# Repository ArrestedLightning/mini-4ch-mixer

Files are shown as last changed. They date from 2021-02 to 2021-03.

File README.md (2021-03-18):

# Mini 4 Channel Audio Mixer

A very simple active audio mixer with 4 3.5mm inputs, and 1 3.5mm output.  USB-powered.  The default gain is 1:1 on all channels, although this can be changed by altering resistor values and/or installing potentiometers.  I built this as a simple way to run multiple sources into a set of computer speakers.  It is designed to fit in a commonly-available 90x70x28mm enclosure with end panels that can be either laser-cut or made from PCBs.

This project uses symbols from https://github.com/ArrestedLightning/al_kicad_libraries/.  It is licensed CC BY 4.0.

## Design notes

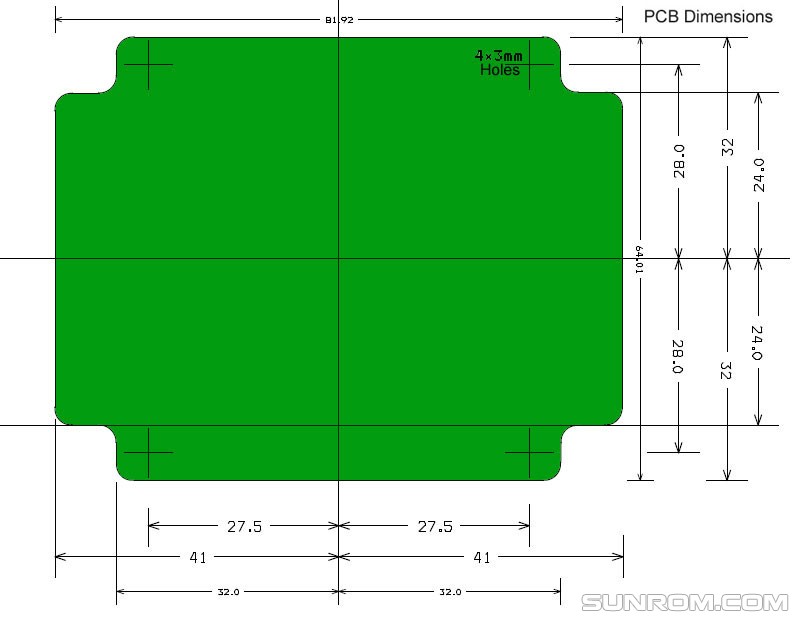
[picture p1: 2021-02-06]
artwork/pcbdim.jpg

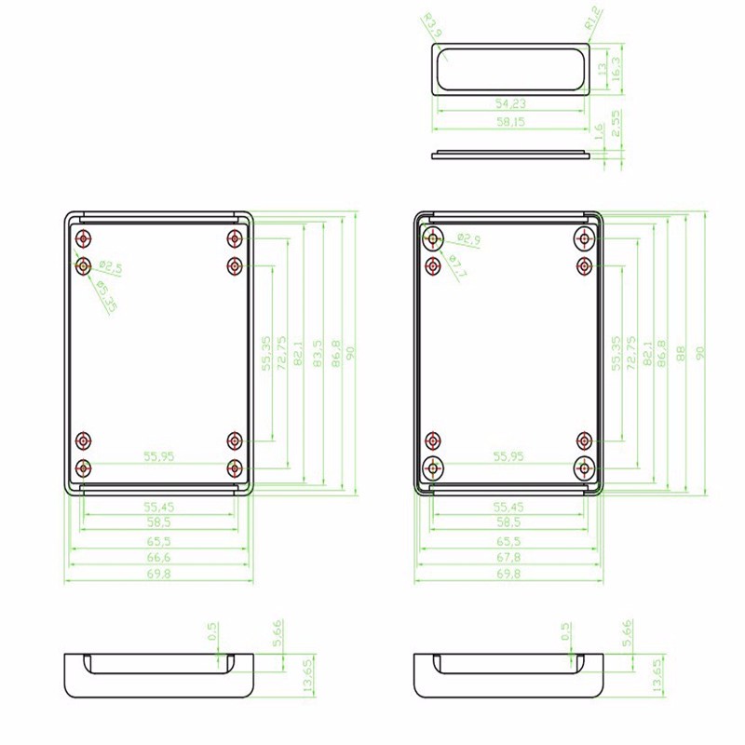
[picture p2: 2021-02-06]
artwork/casedim2.jpg

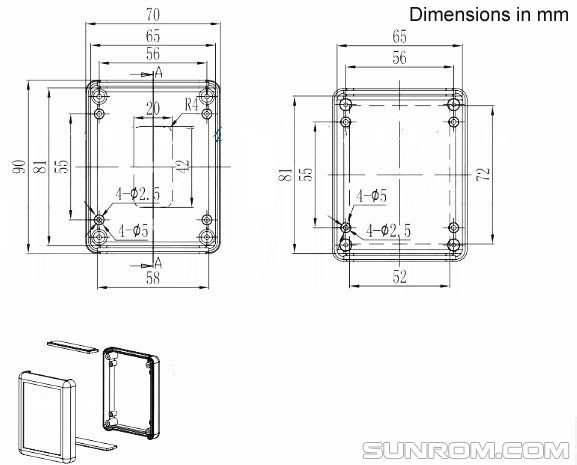
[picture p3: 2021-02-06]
artwork/casedim1.jpg

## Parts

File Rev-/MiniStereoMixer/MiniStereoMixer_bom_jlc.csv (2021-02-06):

Comment | Designator | Footprint | LCSC Part #
0.1uF | C14,C1,C2 | C_0805_2012Metric_Pad1.15x1.40mm_HandSolder | C49678
1uF | C15,C6,C10 | C_0805_2012Metric_Pad1.15x1.40mm_HandSolder | C28323
10uF | C17,C16,C18,C7,C11,C8,C12,C9,C13,C3,C5,C4,C19 | C_0805_2012Metric_Pad1.15x1.40mm_HandSolder | C15850
Blue | D1 | LED_0805_2012Metric_Pad1.15x1.40mm_HandSolder | C2293
White | D2 | LED_0805_2012Metric_Pad1.15x1.40mm_HandSolder | C34499
Ferrite_Bead_Small | FB1,FB2,FB3 | R_0805_2012Metric_Pad1.15x1.40mm_HandSolder | C1017
82K | R3,R6 | R_0805_2012Metric_Pad1.15x1.40mm_HandSolder | C17840
220K | R4,R5 | R_0805_2012Metric_Pad1.15x1.40mm_HandSolder | C17556
0 | R11,R13,R12,R14,R10,R9,R8,R7,R29 | R_0805_2012Metric_Pad1.15x1.40mm_HandSolder | C17477
10K | R23,R24,R18,R17,R16,R15,R19,R20,R21,R22 | R_0805_2012Metric_Pad1.15x1.40mm_HandSolder | C17414
100 | R25,R26 | R_0805_2012Metric_Pad1.15x1.40mm_HandSolder | C17408
4.7K | R27,R28 | R_0805_2012Metric_Pad1.15x1.40mm_HandSolder | C17673
LM27762 | U1 | WSON-12-1EP_3x2mm_P0.5mm_EP1x2.65_ThermalVias | C134018
TL072 | U2 | SO-8_3.9x4.9mm_P1.27mm | C6961

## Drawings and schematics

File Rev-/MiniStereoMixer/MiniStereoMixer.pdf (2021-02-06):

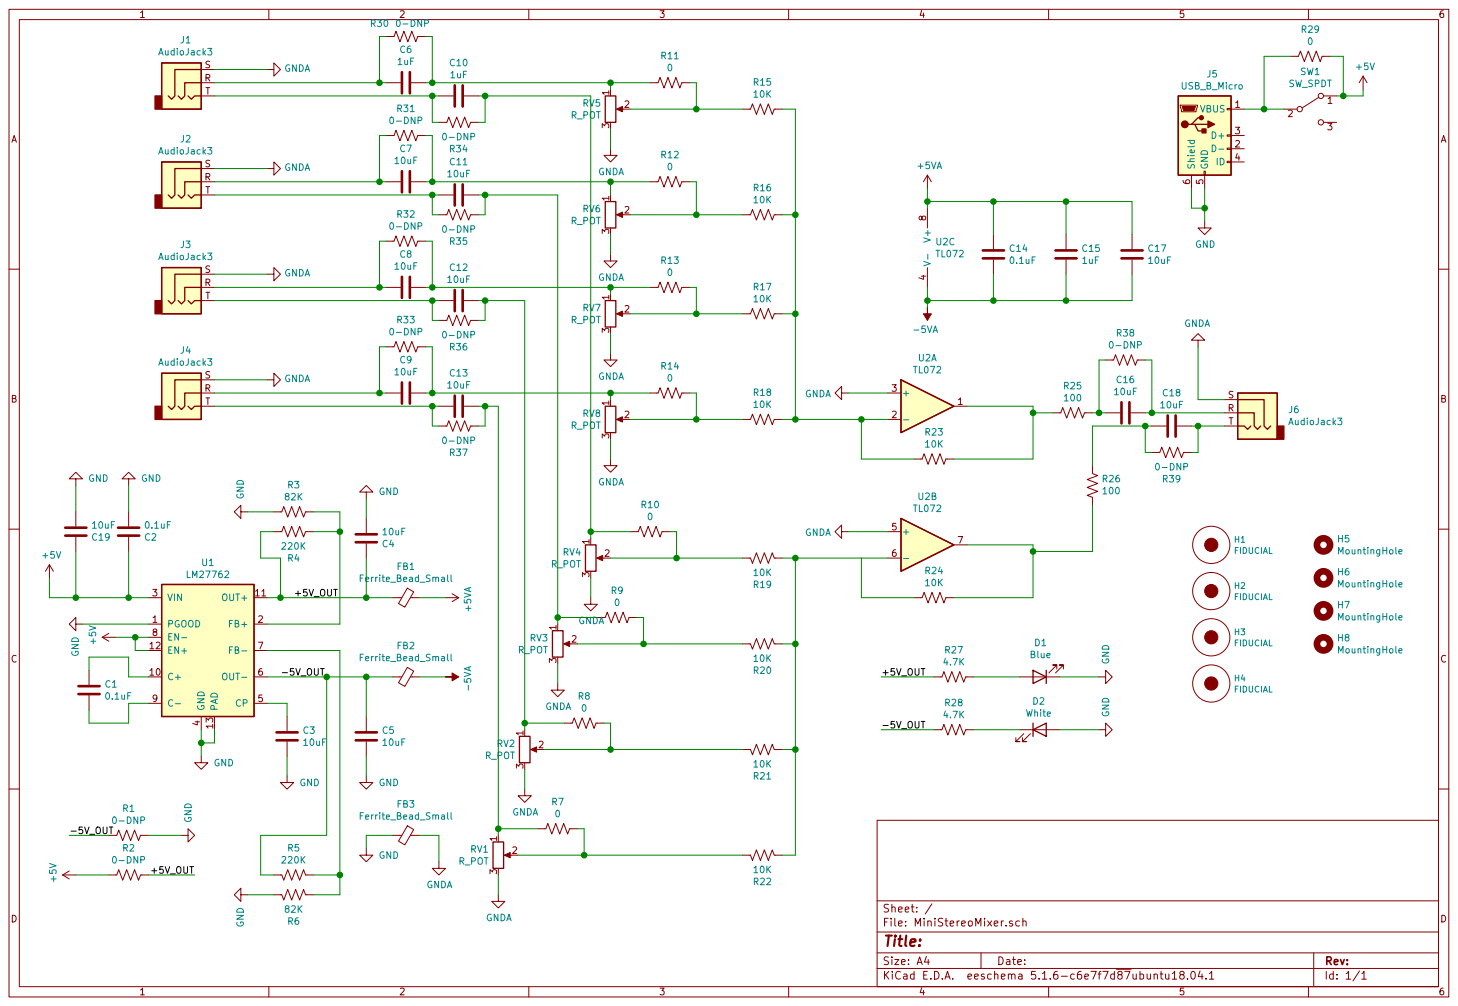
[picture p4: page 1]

Id: 1/1 Title: File: MiniStereoMixer.sch Sheet: / GND

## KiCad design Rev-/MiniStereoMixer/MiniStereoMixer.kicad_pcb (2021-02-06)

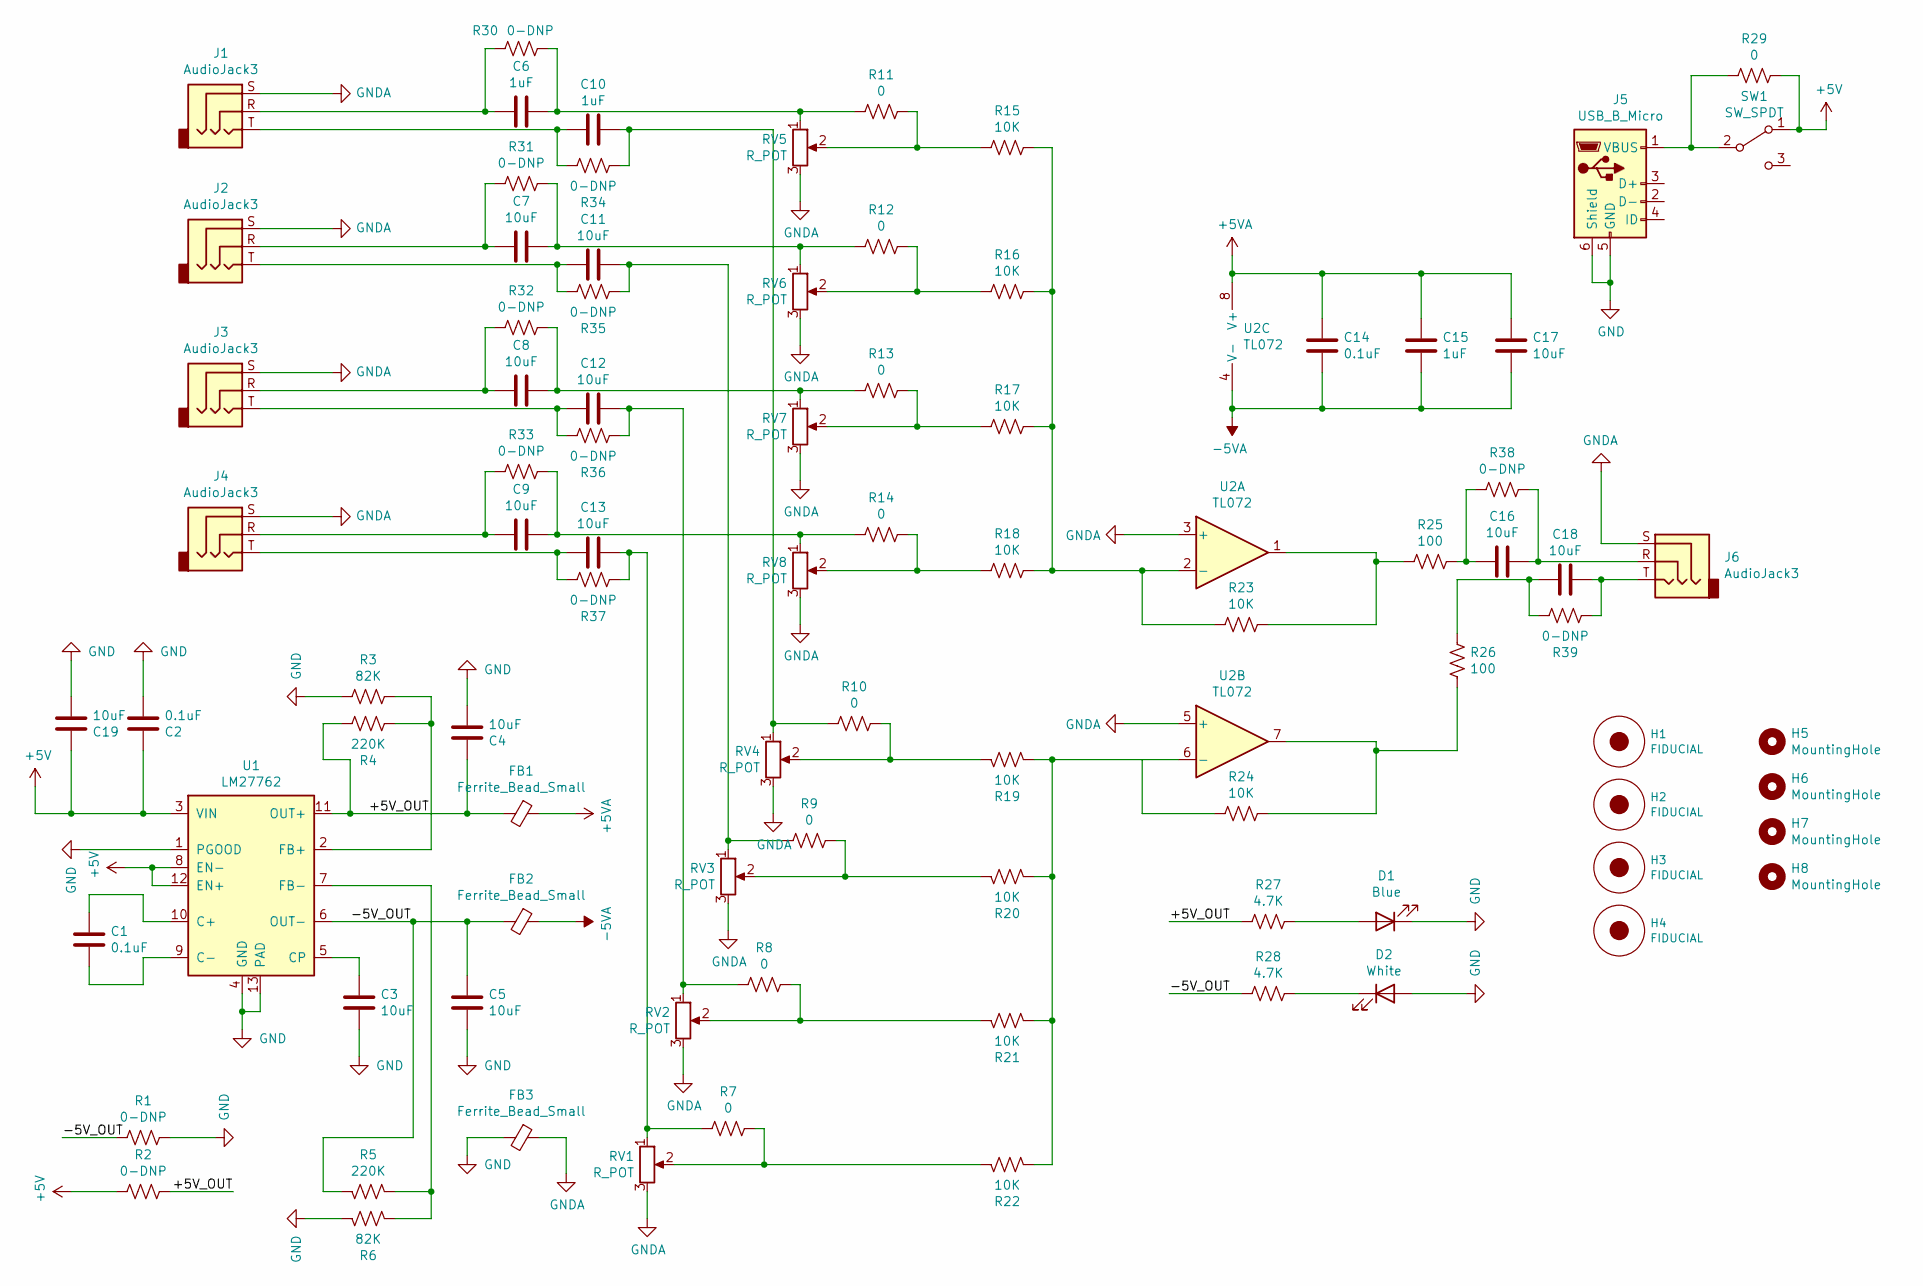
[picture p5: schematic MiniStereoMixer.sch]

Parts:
C1, C2, C14: 0.1uF; C_0805_2012Metric_Pad1.15x1.40mm_HandSolder; JLCPCB C49678
C3, C4, C5, C7, C8, C9, C11, C12, C13, C16, C17, C18, C19: 10uF; C_0805_2012Metric_Pad1.15x1.40mm_HandSolder; JLCPCB C15850
C6, C10, C15: 1uF; C_0805_2012Metric_Pad1.15x1.40mm_HandSolder; JLCPCB C28323
D1: Blue; LED_0805_2012Metric_Pad1.15x1.40mm_HandSolder; JLCPCB C2293
D2: White; LED_0805_2012Metric_Pad1.15x1.40mm_HandSolder; JLCPCB C34499
FB1, FB2, FB3: Ferrite_Bead_Small; R_0805_2012Metric_Pad1.15x1.40mm_HandSolder; JLCPCB C1017
H1, H2, H3, H4: FIDUCIAL; Fiducial_1.5mm_Mask3mm
H5, H6, H7, H8: MountingHole; MountingHole_3.2mm_M3_Pad
J1, J2, J3, J4, J6: AudioJack3; 3.5mmAudioJack
J5: USB_B_Micro; USB_Micro_A_SMD_HANDSOLDER_SMALLPADS
R1, R2, R30, R31, R32, R33, R34, R35, R36, R37, R38, R39: 0-DNP; R_0805_2012Metric_Pad1.15x1.40mm_HandSolder
R3, R6: 82K; R_0805_2012Metric_Pad1.15x1.40mm_HandSolder; JLCPCB C17840
R4, R5: 220K; R_0805_2012Metric_Pad1.15x1.40mm_HandSolder; JLCPCB C17556
R7, R8, R9, R10, R11, R12, R13, R14, R29: 0; R_0805_2012Metric_Pad1.15x1.40mm_HandSolder; JLCPCB C17477
R15, R16, R17, R18, R19, R20, R21, R22, R23, R24: 10K; R_0805_2012Metric_Pad1.15x1.40mm_HandSolder; JLCPCB C17414
R25, R26: 100; R_0805_2012Metric_Pad1.15x1.40mm_HandSolder; JLCPCB C17408
R27, R28: 4.7K; R_0805_2012Metric_Pad1.15x1.40mm_HandSolder; JLCPCB C17673
RV1, RV2, RV3, RV4, RV5, RV6, RV7, RV8: R_POT; potentiometer_3x5mm
SW1: SW_SPDT; PinHeader_1x03_P2.54mm_Horizontal
U1: LM27762; WSON-12-1EP_3x2mm_P0.5mm_EP1x2.65_ThermalVias; JLCPCB C134018
U2: TL072; SO-8_3.9x4.9mm_P1.27mm; JLCPCB C6961

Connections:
+5V: C2.1, C19.1, R2.2, R29.1, SW1.1 (A), U1.3 (VIN), U1.8 (EN-), U1.12 (EN+)
+5VA: C14.1, C15.1, C17.1, FB1.1, U2.8 (V+)
-5VA: C14.2, C15.2, C17.2, FB2.1, U2.4 (V-)
/+5V_OUT: C4.1, FB1.2, R2.1, R4.1, R27.2, U1.11 (OUT+)
/-5V_OUT: C5.1, FB2.2, R1.2, R5.1, R28.2, U1.6 (OUT-)
GND: C2.2, C3.2, C4.2, C5.2, C19.2, D1.1 (K), D2.2 (A), FB3.2, J5.5 (GND), J5.6 (Shield), R1.1, R3.2, R6.2, U1.1 (PGOOD), U1.4 (GND), U1.13 (PAD)
GNDA: FB3.1, J1.S, J2.S, J3.S, J4.S, J6.S, RV1.3, RV2.3, RV3.3, RV4.3, RV5.3, RV6.3, RV7.3, RV8.3, U2.3 (+), U2.5 (+)
unnamed: C1.1, U1.10 (C+)
unnamed: C1.2, U1.9 (C-)
unnamed: C3.1, U1.5 (CP)
unnamed: C6.1, R11.2, R30.1, RV5.1
unnamed: C6.2, J1.R, R30.2
unnamed: C7.1, R12.2, R31.1, RV6.1
unnamed: C7.2, J2.R, R31.2
unnamed: C8.1, R13.2, R32.1, RV7.1
unnamed: C8.2, J3.R, R32.2
unnamed: C9.1, R14.2, R33.1, RV8.1
unnamed: C9.2, J4.R, R33.2
unnamed: C10.1, R10.2, R34.2, RV4.1
unnamed: C10.2, J1.T, R34.1
unnamed: C11.1, R9.2, R35.2, RV3.1
unnamed: C11.2, J2.T, R35.1
unnamed: C12.1, R8.2, R36.2, RV2.1
unnamed: C12.2, J3.T, R36.1
unnamed: C13.1, R7.2, R37.2, RV1.1
unnamed: C13.2, J4.T, R37.1
unnamed: C16.1, J6.R, R38.1
unnamed: C16.2, R25.1, R38.2
unnamed: C18.1, J6.T, R39.2
unnamed: C18.2, R26.2, R39.1
unnamed: D1.2 (A), R27.1
unnamed: D2.1 (K), R28.1
unnamed: J5.1 (VBUS), R29.2, SW1.2 (B)
unnamed: R3.1, R4.2, U1.2 (FB+)
unnamed: R5.2, R6.1, U1.7 (FB-)
unnamed: R10.1, R19.2, RV4.2
unnamed: R11.1, R15.2, RV5.2
unnamed: R12.1, R16.2, RV6.2
unnamed: R13.1, R17.2, RV7.2
unnamed: R14.1, R18.2, RV8.2
unnamed: R15.1, R16.1, R17.1, R18.1, R23.2, U2.2 (-)
unnamed: R19.1, R20.1, R21.1, R22.1, R24.2, U2.6 (-)
unnamed: R9.1, R20.2, RV3.2
unnamed: R8.1, R21.2, RV2.2
unnamed: R7.1, R22.2, RV1.2
unnamed: R23.1, R25.2, U2.1
unnamed: R24.1, R26.1, U2.7

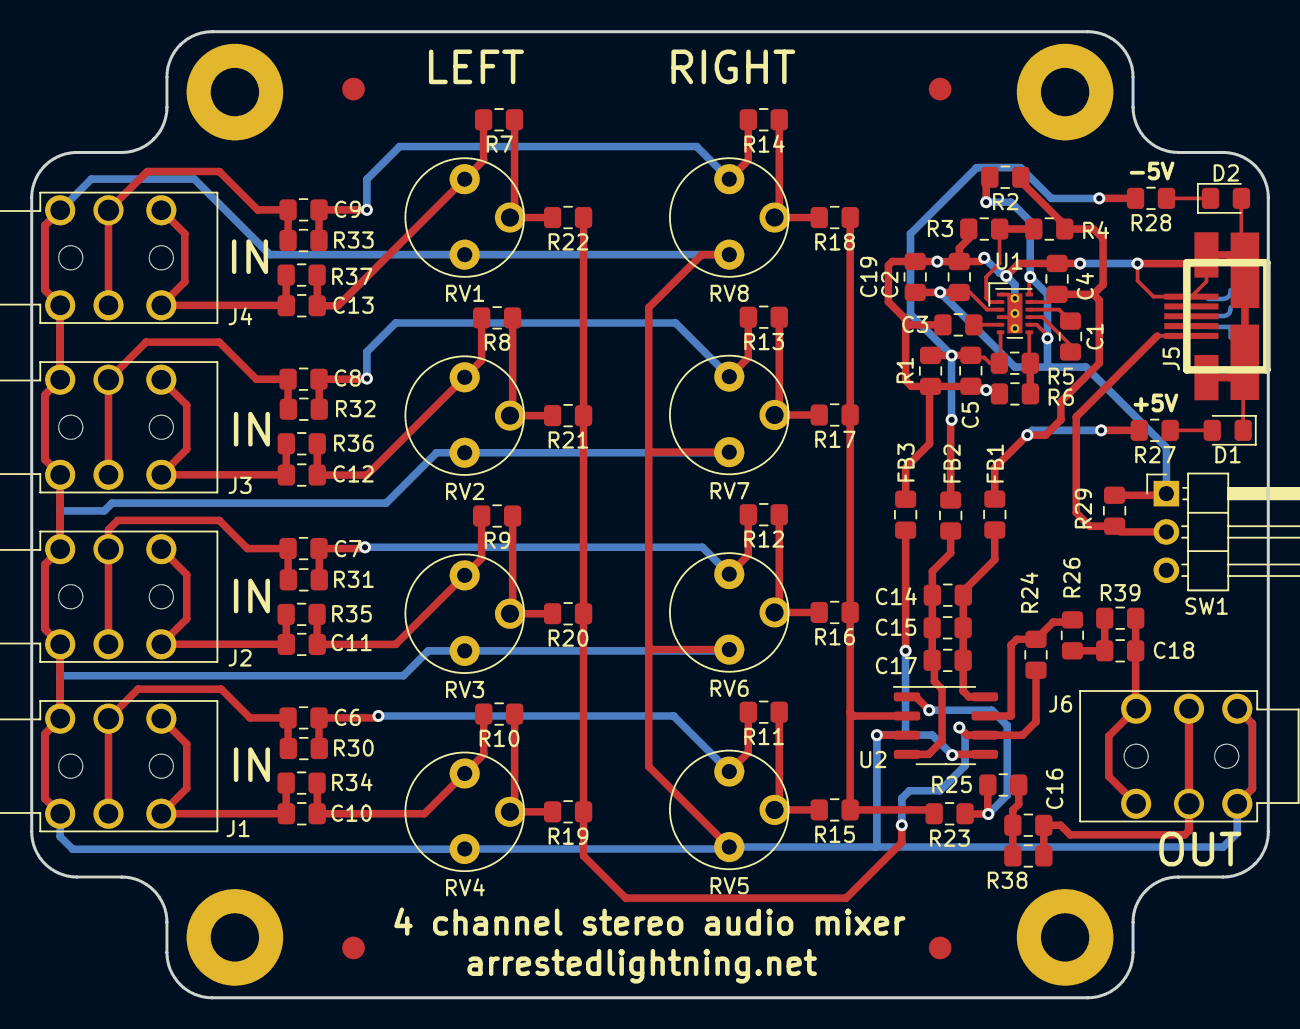
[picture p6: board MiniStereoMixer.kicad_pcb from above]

Board: 2 copper layers, 81.9 x 64.0 mm, 88 parts (0 on the bottom side), 47 nets.
